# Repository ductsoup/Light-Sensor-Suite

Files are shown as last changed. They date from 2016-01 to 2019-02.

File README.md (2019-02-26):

# Light-Sensor-Suite
A low cost but capable WiFi ambient light sensor for advanced daylight harvesting applications.

The hardware was prototyped and refined using [Adafruit IO beta](https://io.adafruit.com), the firmware was tested using [Inductive Automation's Ignition](https://inductiveautomation.com/scada-software/) product.

## Overview
Effective daylight harvesting is difficult to implement in industrial environments using commercial lighting controllers because the natural sunlight contribution changes rapidly and varies widely over the course of the day. If the source of the daylight is side lighting, the challenge becomes nearly impossible.

A more practical approach is to use either fluorescent or LED dimmable fixtures over task areas then use a down looking light sensor as feedback to modulate the artificial light and consistently maintain any given light level at the work plane.

Commercial light sensors are relatively expensive to install, have limited sensitiviety, and are prone to noise because  they typically use a 0-10V analog signal. The goal here is to adapt widely available, inexpensive and very accurate smart phone sensor technology for use in an industrial environment to provide a clean, digital, floating point value that's more accurate and inherently immune to noise.

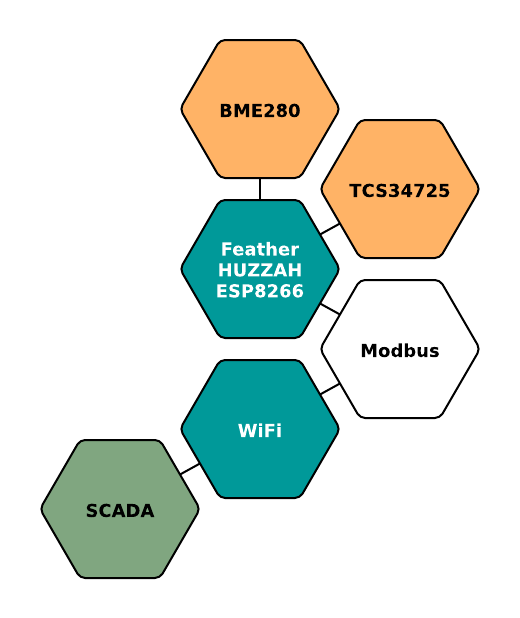
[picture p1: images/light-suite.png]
LSS Overview


## Design Notes
This suite is intended to be mounted in the ceiling at the level of the light fixtures looking down at the task area. The enclosure is a cover that fits a standard 4x4 electrical junction box.

Rather than interface directly, this suite simply logs data to a SCADA system which makes it available to the lighting controllers. The lighting controller's PLC logic should be coded to use the information if available but not depend on it for normal operation. 

The lighting controller PLC supplies 24VDC. A [TSR 1-2450] (https://www.adafruit.com/products/1065) buck converter (supply 6.5 to 36VDC) is used to provde 5VDC to the [Adafruit Feather HUZZAH ESP8266] (https://www.adafruit.com/products/2821). The ESP8266's regulator supplies 3.3VDC to the sensor breakout boards.

Both sensor breakout boards communicate with the ESP8266 over I2C. Other I2C sensors can easily be added as needed depending on the application.

A [TCS34725] (https://www.adafruit.com/products/1334) is used for light level and color temperature sensing. Color temperature sensing introduces the opportunity to discriminate between artificial and natural light. A [BME280] (https://www.adafruit.com/products/2652) is used for temperature, humidity and barometric pressure sening. The BME280 is not required for this application but provides useful data for managing destratification, heating and cooling systems.

## MODBUS Holding Register Map (Float encoding, reversed word order)
All registers are read only unless otherwise indicated.

### S0 - ESP8266 
**40001 S0_Available**

Always 1 if the suite is connected and operating. 

**40003 S0_ScanTime**

The number of milliseconds it took to update the S0 data.

**40005 S0_CurrentMillis**

The number of milliseconds since the suite booted. This is natively an unsigned long value and will eventually wrap.

**40007 S0_RSSI**

The WiFi signal strength.

### S1 - TCS34725

**40009 S1_Available**

A value of 1 indicates the sensor is connected and reporting, otherwise the value will be 0.

**40011 S1_ScanTime**

The number of milliseconds it took to update the S1 data.

**40013 S1_Lux**

The most recent light level in lux.

**40015 S1_CT**

The most recent color temperature in Kelvin.

**40017 S1_IR**

The most recent IR correction value.

**40019 S1_AGAINX**

The current gain.

**40021 S1_ATIME_MS, 40023 S1_ATIME**

The current integration time.

**40025 S1_R_RAW, 40027 S1_G_RAW, 40029 S1_B_RAW, 40031 S1_C_RAW**

The most recent raw sensor data for the R, G, B and C channels.

**40033 S1_R_COMP, 40035 S1_G_COMP, 40037 S1_B_COMP, 40039 S1_C_COMP**

The most recent IR compensated sensor data for the R, G, B and C channels.

### S2 - BME280

**40041 S2_Available**

A value of 1 indicates the sensor is connected and reporting, otherwise the value will be 0.

**40043 S2_ScanTime**

The number of milliseconds it took to update the S2 data.

**40045 S2_SeaLevelPressureHPA**  

This register is read/write and contains the sea level pressure used to calculate altitude.

**40047 S2_Temperature**

The most recent temperature in Fahrenheit.

**40049 S2_Pressure**

The most recent atmospheric pressure in inches of mercury.

**40051 S2_Altitude**

The most recent calculated altitude in feet.

**40053 S2_Humidity**

The most recent relative humidity.

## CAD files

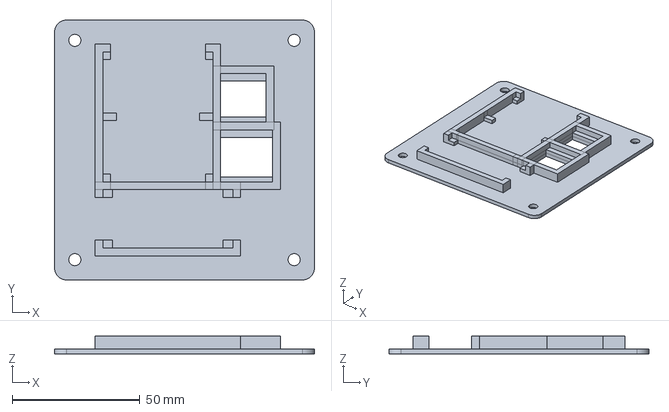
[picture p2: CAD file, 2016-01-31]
hardware/enclosure/alt.stp
101.6 x 101.6 x 7.00 mm

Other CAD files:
hardware/enclosure/light-sensor-suite.stp
hardware/enclosure/alt.3dm
hardware/enclosure/alt.stl
hardware/enclosure/light-sensor-suite.3dm
hardware/enclosure/light-sensor-suite.stl

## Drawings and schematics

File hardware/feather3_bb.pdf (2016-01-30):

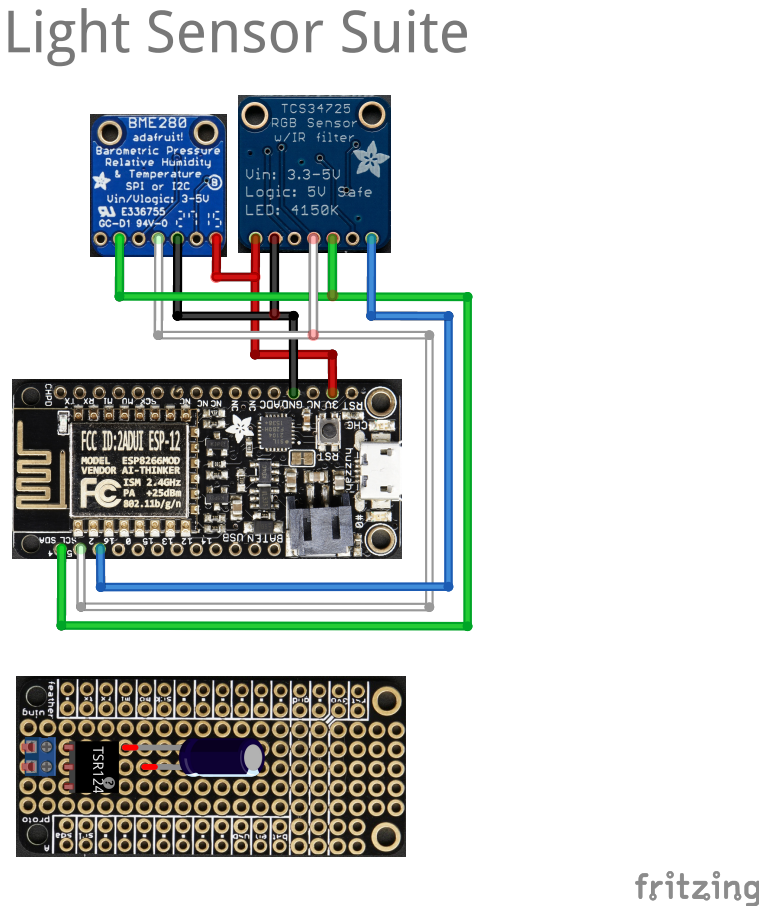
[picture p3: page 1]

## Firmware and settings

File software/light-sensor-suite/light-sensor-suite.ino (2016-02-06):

/***************************************************************************
  light-sensor-suite firmware

  This sketch makes I2C sensor data available to a ModbusTCP protocol master over WiFi.

  https://github.com/ductsoup/Light-Sensor-Suite

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
  THE SOFTWARE IS PROVIDED "AS IS", WITHOUT WARRANTY OF ANY KIND, EXPRESS OR
  IMPLIED, INCLUDING BUT NOT LIMITED TO THE WARRANTIES OF MERCHANTABILITY,
  FITNESS FOR A PARTICULAR PURPOSE AND NONINFRINGEMENT. IN NO EVENT SHALL THE
  AUTHORS OR COPYRIGHT HOLDERS BE LIABLE FOR ANY CLAIM, DAMAGES OR OTHER
  LIABILITY, WHETHER IN AN ACTION OF CONTRACT, TORT OR OTHERWISE, ARISING FROM,
  OUT OF OR IN CONNECTION WITH THE SOFTWARE OR THE USE OR OTHER DEALINGS IN
  THE SOFTWARE. 
  ***************************************************************************/

#define WLAN_SSID  "yourSSID"
#define WLAN_PASS  "yourPassword"

/***************************************************************************
  This is a library for the BME280 humidity, temperature & pressure sensor

  Designed specifically to work with the Adafruit BME280 Breakout
  ----> http://www.adafruit.com/products/2650

  These sensors use I2C or SPI to communicate, 2 or 4 pins are required
  to interface.

  Adafruit invests time and resources providing this open source code,
  please support Adafruit andopen-source hardware by purchasing products
  from Adafruit!

  Written by Limor Fried & Kevin Townsend for Adafruit Industries.
  BSD license, all text above must be included in any redistribution
 ***************************************************************************/

#include <Wire.h>
#include "Adafruit_TCS34725.h"
//
// An experimental wrapper class that implements the improved lux and color temperature from
// TAOS and a basic autorange mechanism.
//
// Written by ductsoup, public domain
//

// RGB Color Sensor with IR filter and White LED - TCS34725
// I2C 7-bit address 0x29, 8-bit address 0x52
//
// http://www.adafruit.com/product/1334
// http://learn.adafruit.com/adafruit-color-sensors/overview
// http://www.adafruit.com/datasheets/TCS34725.pdf
// http://www.ams.com/eng/Products/Light-Sensors/Color-Sensor/TCS34725
// http://www.ams.com/eng/content/view/download/265215 <- DN40, calculations
// http://www.ams.com/eng/content/view/download/181895 <- DN39, some thoughts on autogain
// http://www.ams.com/eng/content/view/download/145158 <- DN25 (original Adafruit calculations)
//
// connect LED to digital 4 or GROUND for ambient light sensing
// connect SCL to analog 5
// connect SDA to analog 4
// connect Vin to 3.3-5V DC
// connect GROUND to common ground

// some magic numbers for this device from the DN40 application note
#define TCS34725_R_Coef 0.136
#define TCS34725_G_Coef 1.000
#define TCS34725_B_Coef -0.444
#define TCS34725_GA 1.0
#define TCS34725_DF 310.0
#define TCS34725_CT_Coef 3810.0
#define TCS34725_CT_Offset 1391.0

// Autorange class for TCS34725
class tcs34725 {
  public:
    tcs34725(void);

    boolean begin(void);
    void getData(void);

    boolean isAvailable, isSaturated;
    uint16_t againx, atime, atime_ms;
    uint16_t r, g, b, c;
    uint16_t ir;
    uint16_t r_comp, g_comp, b_comp, c_comp;
    uint16_t saturation, saturation75;
    float cratio, cpl, ct, lux, maxlux;

  private:
    struct tcs_agc {
      tcs34725Gain_t ag;
      tcs34725IntegrationTime_t at;
      uint16_t mincnt;
      uint16_t maxcnt;
    };
    static const tcs_agc agc_lst[];
    uint16_t agc_cur;

    void setGainTime(void);
    Adafruit_TCS34725 tcs;
};
//
// Gain/time combinations to use and the min/max limits for hysteresis
// that avoid saturation. They should be in order from dim to bright.
//
// Also set the first min count and the last max count to 0 to indicate
// the start and end of the list.
//
const tcs34725::tcs_agc tcs34725::agc_lst[] = {
  { TCS34725_GAIN_60X, TCS34725_INTEGRATIONTIME_700MS,     0, 47566 },
  { TCS34725_GAIN_16X, TCS34725_INTEGRATIONTIME_154MS,  3171, 63422 },
  { TCS34725_GAIN_4X,  TCS34725_INTEGRATIONTIME_154MS, 15855, 63422 },
  { TCS34725_GAIN_1X,  TCS34725_INTEGRATIONTIME_2_4MS,   248,     0 }
};
tcs34725::tcs34725() : agc_cur(0), isAvailable(0), isSaturated(0) {
}

// initialize the sensor
boolean tcs34725::begin(void) {
  tcs = Adafruit_TCS34725(agc_lst[agc_cur].at, agc_lst[agc_cur].ag);
  if ((isAvailable = tcs.begin()))
    setGainTime();
  return (isAvailable);
}

// Set the gain and integration time
void tcs34725::setGainTime(void) {
  tcs.setGain(agc_lst[agc_cur].ag);
  tcs.setIntegrationTime(agc_lst[agc_cur].at);
  atime = int(agc_lst[agc_cur].at);
  atime_ms = ((256 - atime) * 2.4);
  switch (agc_lst[agc_cur].ag) {
    case TCS34725_GAIN_1X:
      againx = 1;
      break;
    case TCS34725_GAIN_4X:
      againx = 4;
      break;
    case TCS34725_GAIN_16X:
      againx = 16;
      break;
    case TCS34725_GAIN_60X:
      againx = 60;
      break;
  }
}

// Retrieve data from the sensor and do the calculations
void tcs34725::getData(void) {
  // read the sensor and autorange if necessary
  tcs.getRawData(&r, &g, &b, &c);
  while (1) {
    if (agc_lst[agc_cur].maxcnt && c > agc_lst[agc_cur].maxcnt)
      agc_cur++;
    else if (agc_lst[agc_cur].mincnt && c < agc_lst[agc_cur].mincnt)
      agc_cur--;
    else break;

    setGainTime();
    delay((256 - atime) * 2.4 * 4); // shock absorber
    //delay(2000);
    tcs.getRawData(&r, &g, &b, &c);
    break;
  }

  // DN40 calculations
  ir = (r + g + b > c) ? (r + g + b - c) / 2 : 0;
  r_comp = r - ir;
  g_comp = g - ir;
  b_comp = b - ir;
  c_comp = c - ir;
  cratio = float(ir) / float(c);

  saturation = ((256 - atime) > 63) ? 65535 : 1024 * (256 - atime);
  saturation75 = (atime_ms < 150) ? saturation75 = saturation - saturation / 4 : saturation;
  isSaturated = (atime_ms < 150 && c > saturation75) ? 1 : 0;
  cpl = (atime_ms * againx) / (TCS34725_GA * TCS34725_DF);
  maxlux = 65535 / (cpl * 3);

  lux = (TCS34725_R_Coef * float(r_comp) + TCS34725_G_Coef * float(g_comp) + TCS34725_B_Coef * float(b_comp)) / cpl;
  if (lux > 0.1) // 2016-02-06 skip the CT calculation unless lux is greater than 0.1 
    ct = TCS34725_CT_Coef * float(b_comp) / float(r_comp) + TCS34725_CT_Offset;
}

tcs34725 tcs;

#include <SPI.h>
#include <Adafruit_Sensor.h>
#include <Adafruit_BME280.h>

#define BME_SCK 13
#define BME_MISO 12
#define BME_MOSI 11
#define BME_CS 10

#define SEALEVELPRESSURE_HPA (1027.8)

Adafruit_BME280 bme; // I2C

// Configure MODBUS over WiFi
#include <ESP8266WiFi.h>
#include "ModbusTCP.h"

// MODBUS holding register map (float)

#define S0_Available            40001
#define S0_ScanTime             40003
#define S0_CurrentMillis        40005
#define S0_RSSI                 40007

#define S1_Available            40009
#define S1_ScanTime             40011
#define S1_Calibration          40013
#define S1_Lux                  40015
#define S1_CT                   40017
#define S1_IR                   40019
#define S1_AGAINX               40021
#define S1_ATIME_MS             40023
#define S1_ATIME                40025
#define S1_R_RAW                40027
#define S1_G_RAW                40029
#define S1_B_RAW                40031 
#define S1_C_RAW                40033
#define S1_R_COMP               40035
#define S1_G_COMP               40037
#define S1_B_COMP               40039
#define S1_C_COMP               40041

#define S2_Available            40043
#define S2_ScanTime             40045
#define S2_SeaLevelPressureHPA  40047  
#define S2_Temperature          40049
#define S2_Pressure             40051
#define S2_Altitude             40053
#define S2_Humidity             40055

bool s1, s2; // flags to indicate which sensors are available

ModbusTCP m;

void setup() {
  // Setup serial port access.
  Serial.begin(115200);
  delay(10);
  Serial.println(); Serial.println();
  Serial.println("2016-02-01 light-sensor-suite");

  // Connect to WiFi access point
  m.begin(WLAN_SSID, WLAN_PASS);
  m.setFloat(S0_Available, 1);

  // Initialize S1
  Serial.print("S1 - TCS34725 ");
  Serial.println((s1 = tcs.begin()) ? "initialized" : "error");
  m.setFloat(S1_Available, (float) s1);
  m.setFloat(S1_Calibration, 1.0);

  // Initialize S2
  Serial.print("S2 - BME280 ");
  Serial.println((s2 = bme.begin()) ? "initialized" : "error");
  m.setFloat(S2_Available, (float) s2);
  m.setFloat(S2_SeaLevelPressureHPA, SEALEVELPRESSURE_HPA);

  pinMode(2, OUTPUT); // If all went well turn the white LED on the TCS off
  if (s1 && s2)
    digitalWrite(2, LOW);
}

#define MAX_SCAN  1000
unsigned long S0StartTime = 0, S1StartTime = MAX_SCAN, S2StartTime = 2 * MAX_SCAN;

void loop() {

  unsigned long curMillis = millis();

  // update S0 registers
  if (curMillis - S0StartTime > 1000) {
    m.setFloat(S0_CurrentMillis, curMillis);
    m.setFloat(S0_RSSI, m.RSSI());
    m.setFloat(S0_ScanTime, millis() - curMillis);
    S0StartTime = curMillis;
  }

  // update S1 registers
  while (s1 && (curMillis - S1StartTime > 5000)) {
    tcs.getData();
    m.setFloat(S1_Lux, m.getFloat(S1_Calibration) * tcs.lux);
    m.setFloat(S1_CT, tcs.ct);
    m.setFloat(S1_IR, tcs.ir);
    m.setFloat(S1_AGAINX, tcs.againx);
    m.setFloat(S1_ATIME_MS, tcs.atime_ms);
    m.setFloat(S1_AGAINX, tcs.atime);
    m.setFloat(S1_R_RAW, tcs.r);
    m.setFloat(S1_G_RAW, tcs.g);
    m.setFloat(S1_B_RAW, tcs.b);
    m.setFloat(S1_C_RAW, tcs.c);
    m.setFloat(S1_R_COMP, tcs.r_comp);
    m.setFloat(S1_G_COMP, tcs.g_comp);
    m.setFloat(S1_B_COMP, tcs.b_comp);
    m.setFloat(S1_C_COMP, tcs.c_comp);
    m.setFloat(S1_ScanTime, millis() - curMillis);
    S1StartTime = curMillis;
  }

  // update S2 registers
  while (s2 && (curMillis - S2StartTime > 10000)) {
    m.setFloat(S2_Temperature, (9.0 / 5.0) * bme.readTemperature() + 32.0); // in F
    m.setFloat(S2_Pressure, 0.02953 * bme.readPressure() / 100.0F); // in InHG
    m.setFloat(S2_Altitude, 3.28084 * bme.readAltitude(m.getFloat(S2_SeaLevelPressureHPA))); // in feet
    m.setFloat(S2_Humidity, bme.readHumidity());
    m.setFloat(S2_ScanTime, millis() - curMillis);
    S2StartTime = curMillis;
  }

  // process MODBUS requests
  m.run();
  delay(10);
}

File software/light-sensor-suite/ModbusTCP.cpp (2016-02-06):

/*******************************************************************************
 * ModbusTCP.cpp
 */
#include <Arduino.h>
#include "ModbusTCP.h"

ModbusTCP::ModbusTCP(void) :
#ifdef MB_ETHERNET
  mb_server(MB_PORT)
#endif
#ifdef MB_CC3000
  mb_client(ADAFRUIT_CC3000_CS, ADAFRUIT_CC3000_IRQ, ADAFRUIT_CC3000_VBAT, SPI_CLOCK_DIVIDER),
  mb_server(MB_PORT)
#endif
#ifdef MB_ESP8266
  mb_server(MB_PORT)
#endif
{
}
#ifdef MB_ETHERNET
void ModbusTCP::begin(uint8_t mac[6]) {

  Serial.print(F("Requesting DHCP ..."));
  if (Ethernet.begin(mac) == 0) {
    Serial.println("failed");
    while (1);
  }
  else
    Serial.println();

  Serial.print(F("Listening on "));
  for (byte thisByte = 0; thisByte < 4; thisByte++) {
    Serial.print(Ethernet.localIP()[thisByte], DEC);
    Serial.print(thisByte < 3 ? "." : "");
  }
  Serial.print(":");
  Serial.print(MB_PORT);
  Serial.println(" ...");
}
#endif
#ifdef MB_CC3000
void ModbusTCP::begin(const char *ssid, const char *key, uint8_t secmode) {

  mb_client.begin();
  Serial.print(F("Connecting to ")); Serial.print(ssid); Serial.println(F(" ..."));
  mb_client.connectToAP(ssid, key, secmode);
  while (!mb_client.checkDHCP())
    delay(100);
  uint32_t ipAddress, netmask, gateway, dhcpserv, dnsserv;
  mb_client.getIPAddress(&ipAddress, &netmask, &gateway, &dhcpserv, &dnsserv);
  Serial.print(F("Listening on "));
  mb_client.printIPdotsRev(ipAddress);
  Serial.print(F(":"));
  Serial.println(MB_PORT);
  mb_server.begin();
}
#endif
#ifdef MB_ESP8266
void ModbusTCP::begin(const char *ssid, const char *key) {
  pinMode(LED_PIN, OUTPUT);
  digitalWrite(LED_PIN, LOW);
  ledPinStatus = LOW;
#ifdef MB_DEBUG
  Serial.begin(115200);
  // Connect to WiFi network
  Serial.println();
  Serial.println();
  Serial.print("Connecting to ");
  Serial.println(ssid);
#endif

  WiFi.begin(ssid, key);

  while (WiFi.status() != WL_CONNECTED) {
    // Blink the LED
    digitalWrite(LED_PIN, ledPinStatus); // Write LED high/low
    ledPinStatus = (ledPinStatus == HIGH) ? LOW : HIGH;
    delay(100);
#ifdef MB_DEBUG
    Serial.print(".");
#endif
  }
#ifdef MB_DEBUG
  Serial.println("");
  Serial.println("WiFi connected");
#endif

#ifdef MB_DEBUG
  Serial.print("IP address: ");
  Serial.println(WiFi.localIP());
  Serial.print("WiFi signal");
  Serial.println(WiFi.RSSI());
  byte mac[6];
  WiFi.macAddress(mac);
  Serial.print("MAC: ");
  Serial.print(mac[0], HEX); Serial.print(":");
  Serial.print(mac[1], HEX); Serial.print(":");
  Serial.print(mac[2], HEX); Serial.print(":");
  Serial.print(mac[3], HEX); Serial.print(":");
  Serial.print(mac[4], HEX); Serial.print(":");
  Serial.print(mac[5], HEX); Serial.println();  
#endif

  // Start the server
  digitalWrite(LED_PIN, LOW);
  mb_server.begin();
#ifdef MB_DEBUG
  Serial.print(F("Listening on "));
  Serial.print(MB_PORT);
  Serial.println(" ...");
#endif
}
void ModbusTCP::begin(const char *ssid, const char *key, uint8_t ip[4], uint8_t gateway[4], uint8_t subnet[4]) {
  pinMode(LED_PIN, OUTPUT);
  digitalWrite(LED_PIN, LOW);
  ledPinStatus = LOW;
#ifdef MB_DEBUG
  Serial.begin(115200);
  // Connect to WiFi network
  Serial.println();
  Serial.println();
  Serial.print("Connecting to ");
  Serial.println(ssid);
#endif

  WiFi.config(IPAddress(ip), IPAddress(gateway), IPAddress(subnet));

  WiFi.begin(ssid, key);

  while (WiFi.status() != WL_CONNECTED) {
    // Blink the LED
    digitalWrite(LED_PIN, ledPinStatus); // Write LED high/low
    ledPinStatus = (ledPinStatus == HIGH) ? LOW : HIGH;
    delay(100);
#ifdef MB_DEBUG
    Serial.print(".");
#endif
  }
#ifdef MB_DEBUG
  Serial.println("");
  Serial.println("WiFi connected");
  Serial.print("IP address: ");
  Serial.println(WiFi.localIP());
  Serial.print("WiFi signal");
  Serial.println(WiFi.RSSI());
  byte mac[6];
  WiFi.macAddress(mac);
  Serial.print("MAC: ");
  Serial.print(mac[5], HEX); Serial.print(":");
  Serial.print(mac[4], HEX); Serial.print(":");
  Serial.print(mac[3], HEX); Serial.print(":");
  Serial.print(mac[2], HEX); Serial.print(":");
  Serial.print(mac[1], HEX); Serial.print(":");
  Serial.print(mac[0], HEX); Serial.println();
#endif

  // Start the server
  mb_server.begin();
  digitalWrite(LED_PIN, LOW);
#ifdef MB_DEBUG
  Serial.print(F("Listening on "));
  Serial.print(MB_PORT);
  Serial.println(" ...");
#endif
}
#endif

float ModbusTCP::RSSI(void) {
  return (WiFi.RSSI());
}

void ModbusTCP::run(void) {

  int16_t i, iStart, iQty;
  int16_t iTXLen = 0;       // response packet length
  uint8_t *ptr, iFC = MB_FC_NONE, iEC = MB_EC_NONE;
  //
  // Initialize and check for a request from a MODBUS master
  //
#ifdef MB_ETHERNET
  EthernetClient clientrequest = mb_server.available();
  if (clientrequest.available()) {
#endif
#ifdef MB_CC3000
  Adafruit_CC3000_ClientRef clientrequest = mb_server.available();
  if (clientrequest.available()) {
#endif
#ifdef MB_ESP8266
  if (!clientrequest.connected())
    clientrequest = mb_server.available();
  if (clientrequest.available()) {
#endif
    //
    // Retrieve request
    //
    for (i = 0 ; clientrequest.available() ; i++)
      mb_adu[i] = clientrequest.read();
#ifdef MB_ESP8266
    clientrequest.flush();
#endif
#ifdef MB_DEBUG
    printMB("RX: ", word(mb_adu[MB_TCP_LEN], mb_adu[MB_TCP_LEN + 1]) + 6);
#endif
    //
    // Unpack the function code
    //
    iFC = mb_adu[MB_TCP_FUNC];
  }
  //
  // Handle request
  //
  switch (iFC) {
    case MB_FC_NONE:
      break;
    case MB_FC_READ_REGISTERS:
      //
      // 03 (0x03) Read Holding Registers
      //
      // modpoll -m tcp -t 4:float -r 40001 -c 1 -1 192.168.x.x
      //
      //     [TransID] [ProtID-] [Length-] [Un] [FC] [Start--] [Qty----]
      // RX: 0x00 0x01 0x00 0x00 0x00 0x06 0x01 0x03 0x9C 0x40 0x00 0x02
      //
      //     [TransID] [ProtID-] [Length-] [Un] [FC] [Bc] [float------------]
      // TX: 0x00 0x01 0x00 0x00 0x00 0x07 0x01 0x03 0x04 0x20 0x00 0x47 0xF1
      //
      // 123456.0 = 0x00 0x20 0xF1 0x47 (IEEE 754)
      //
      // Unpack the start and length
      //
      ptr = mb_adu + MB_TCP_DATA;
      iStart = word(*ptr++, *ptr++) - 40000;
      iQty = 2 * word(*ptr++, *ptr);
      //
      // check for valid register addresses
      //
      if (iStart < 0 || (iStart + iQty / 2 - 1) > MB_REGISTERS_MAX) {
        iEC = MB_EC_ILLEGAL_DATA_ADDRESS;
        break;
      }
      //
      // Write data length
      //
      ptr = mb_adu + MB_TCP_DATA;
      *ptr++ = iQty;
      //
      // Write data
      //
      for (i = 0 ; i < iQty / 2 ; i++) {
        *ptr++ = highByte(mb_reg[iStart + i]);
        *ptr++ =  lowByte(mb_reg[iStart + i]);
      }
      iTXLen = iQty + 9;
      break;
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

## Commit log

2016-01-30 Added CAD files for 3D printed enclosure
    [light-sensor-suite.3dm, light-sensor-suite.stl, light-sensor-suite.stp]
2016-01-31 Added alt 3D models
    [alt.3dm, alt.stl, alt.stp]
2016-02-06 minor firmware refinements
    Added a RW variable S1_Calibration and locked out the CT calculation
    below 0.1 lux for better stability in very low light conditions
    [light-sensor-suite.ino]

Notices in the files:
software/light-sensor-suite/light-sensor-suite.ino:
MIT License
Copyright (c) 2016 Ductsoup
